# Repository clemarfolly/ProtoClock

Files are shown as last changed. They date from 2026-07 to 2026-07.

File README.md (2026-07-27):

# ProtoClock

Relógio digital com alarme para **PIC16F84**, construído com componentes simples e disponíveis.




## Funcionalidades

- Relógio com 4 displays de 7 segmentos (HH:MM)
- Ponto decimal piscando (1Hz)
- Alarme configurável (hora e minuto)
- Brilho dos displays controlado por PWM
- Calibração fina do timer via osciloscópio

## Hardware

### Componentes

| Componente | Descrição | Quantidade |
|---|---|---|
| PIC16F84 | Microcontrolador | 1 |
| 4017 | Decodificador decimal | 1 |
| 74HC08 | Quad AND gate | 1 |
| BC558 | Transistor PNP | 1 |
| LTS-6960HR | Display 7 segmentos | 4 |
| BZ1 | Buzzer | 1 |
| Y1 | Cristal 4MHz | 1 |
| R1-R3 | 10kΩ (pull-up botões) | 3 |
| R4 | 1kΩ (base transistor) | 1 |
| R5-R12 | 220Ω (segmentos) | 8 |
| C1-C2 | 22pF (cristal) | 2 |
| C3-C4 | 100nF (desacoplamento) | 2 |
| C5 | 10µF (alimentação) | 1 |
| D1-D2 | LED (ponto decimal) | 2 |
| D3 | 1N4007 (proteção buzzer) | 1 |

### Pinagem

```
PIC16F84
┌────────────────────┐
│ 1 RA2   SPK/MIN   │ ← Speaker + Botão MIN (compartilhado)
│ 2 RA3   PONTO/ALR  │ ← LED Ponto + Botão ALARME (compartilhado)
│ 3 RA4   HORA       │ ← Botão HORA
│ 4 MCLR  RESET      │ ← Reset (10k pull-up)
│ 5 VSS   GND        │
│ 6 RB0              │ → Segmento a
│ 7 RB1              │ → Segmento b
│ 8 RB2              │ → Segmento c
│ 9 RB3              │ → PWM Brilho (74HC08)
│ 10 RB4             │ → Segmento d
│ 11 RB5             │ → Segmento e
│ 12 RB6             │ → Segmento f
│ 13 RB7             │ → Segmento g
│ 14 VDD   +5V       │
│ 15 OSC2            │ ← Cristal 4MHz
│ 16 OSC1            │ ← Cristal 4MHz
│ 17 RA0             │ → 4017 CLK
│ 18 RA1             │ → 4017 RESET
└────────────────────┘
```

### Esquemático

O esquemático completo está em [`ProtoClock.pdf`](ProtoClock.pdf).

## Firmware

### Arquivos

| Arquivo | Descrição |
|---|---|
| `ProtoClock84_Otimizado.c` | Código fonte principal (PIC16F84) |
| `ProtoClock.c` | Código original (PIC16F628A, referência) |
| `c84_Otimizado.bat` | Script de compilação |
| `analise_memoria.py` | Análise de uso de memória |

### Estrutura do Código

```
├── Macros e Defines
│   ├── BIT_SET/CLEAR/FLIP/CHECK — manipulação de bits
│   ├── RESET_4017/CLOCK_4017 — controle do decodificador
│   └── SPK_* — configuração do speaker
│
├── Variáveis Globais
│   ├── Relógio: segundo, minuto, hora
│   ├── Alarme: alarme_minuto, alarme_hora, toca_alarme
│   └── Botões: pushFlag[], pushState[]
│
├── ISR (Interrupção)
│   └── Timer0 ~1ms: contagem de tempo, PWM, speaker
│
├── task1() — 61ms
│   ├── Contagem de tempo (segundo/minuto/hora)
│   ├── Leitura de botões com debounce
│   └── Desligamento do alarme
│
├── task2() — 5ms
│   └── Multiplexação dos displays (4017)
│
├── task3() — 201ms
│   └── Ações dos botões (ajuste tempo/alarme)
│
└── main()
    ├── Inicialização
    ├── Loop principal
    └── Lógica do alarme
```

### Compilação

**Requisitos:**
- [SDCC 4.3.0](http://sdcc.sourceforge.net/) (compilador C para PIC)
- [gputils](http://gputils.sourceforge.net/) (montador e linker)

**Passos:**

```bash
# Compilar (Windows)
c84_Otimizado.bat

# Ou manualmente:
sdcc -S --use-non-free -mpic14 -p16f84 ProtoClock84_Otimizado.c
gpasm -I C:\Programas\gputils\header -o ProtoClock84_Otimizado.o -c ProtoClock84_Otimizado.asm
gplink -O 2 -f 0x00 -r -m -s C:\Programas\gputils\lkr\16f84_g.lkr -o ProtoClock84_Otimizado.hex ProtoClock84_Otimizado.o C:\Programas\SDCC\lib\pic14\libsdcc.lib C:\Programas\SDCC\non-free\lib\pic14\pic16f84.lib
```

**Análise de memória:**

```bash
python analise_memoria.py ProtoClock84_Otimizado.map
```

Saída:
```
--- Program Memory ---
  Codigo real:      930 words  (90.8% da ROM)
  Espaco livre:      94 words  (9.2%)

--- Data Memory ---
  RAM utilizada:   57 bytes / 68 bytes
```

### Calibração do Timer

O cristal de 4MHz não é preciso. O Timer0 precisa de calibração fina:

1. Defina `#define CALIBRACAO 1` no código
2. Compile e grave no PIC
3. Meça a frequência no pino RA3 com osciloscópio
4. Ajuste o valor de `cal` em `main()` até obter ~500Hz (2ms período)
5. Remova `#define CALIBRACAO 1`
6. Recompile

Valor padrão: `cal = 10` (ajustado para ~501Hz)

## Botões

| Botão | Pino | Função |
|---|---|---|
| HORA | RA4 | Ajustar hora / Desligar alarme |
| MIN | RA2 | Ajustar minuto / Desligar alarme* |
| ALARME | RA3 | Segurar para ver/ajustar alarme |

### Operação

**Ver horário:** Exibição padrão nos displays.

**Ajustar relógio:**
- Toque rápido em HORA ou MIN = incrementa 1
- Segurar HORA ou MIN = incremento rápido

**Configurar alarme:**
1. Segurar botão ALARME
2. Enquanto segura, tocar HORA ou MIN para ajustar
3. Displays mostram o horário do alarme
4. Soltar ALARME volta ao horário

**Alarme desabilitado:** Hora = 0 e Minuto = 0

**Desligar alarme:** Pressionar HORA ou ALARME enquanto toca.

> \* **Nota:** O botão MIN compartilha pino RA2 com o speaker. Enquanto o alarme toca, o MIN não funciona. Apenas HORA e ALARME podem desligar.

## Limitações de Hardware

### Pinos Compartilhados

| Pino | Funções | Conflito |
|---|---|---|
| RA2 | Speaker + Botão MIN | Botão MIN inoperante durante alarme |
| RA3 | LED Ponto + Botão ALARME | LED desligado durante leitura do botão |

### Soluções implementadas

- **RA2:** Botão MIN é ignorado enquanto `toca_alarme > 0`
- **RA3:** Pin é alternado entre saída (LED) e entrada (botão) ciclicamente a cada ~61ms

### Recomendações para versão futura

- Usar pinos dedicados para speaker e botões
- Adicionar capacitor 100nF entre MCLR e GND para reset mais confiável
- Considerar PIC16F628A (mais pinos, BOR interno)

## Memória

| Recurso | Total | Utilizado | Livre |
|---|---|---|---|
| ROM (programa) | 1024 words | 930 words | 94 words |
| RAM (dados) | 68 bytes | 57 bytes | 11 bytes |

### Distribuição da ROM

| Seção | Tamanho | Descrição |
|---|---|---|
| task1 | 286w | Leitura de botões + relógio |
| task3 | 164w | Ações dos botões |
| main | 145w | Loop principal + alarme |
| ISR | 129w | Interrupção (Timer0) |
| task2 | 124w | Multiplexação display |
| .code | 19w | Biblioteca _gptrget1 |
| obterNumeroDisplay | 18w | Conversão display |
| obterDecimal | 15w | Extração dezena |
| obterUnidade | 13w | Extração unidade |
| numero[10] | 10w | Tabela de segmentos |
| botaoIO[3] | 3w | Mapeamento botões |

## Esquemático

O esquemático completo está disponível em [`ProtoClock.pdf`](ProtoClock.pdf).

Feito com KiCad E.D.A. 9.0.7.

## Licença

Este é um projeto pessoal. Use como quiser.

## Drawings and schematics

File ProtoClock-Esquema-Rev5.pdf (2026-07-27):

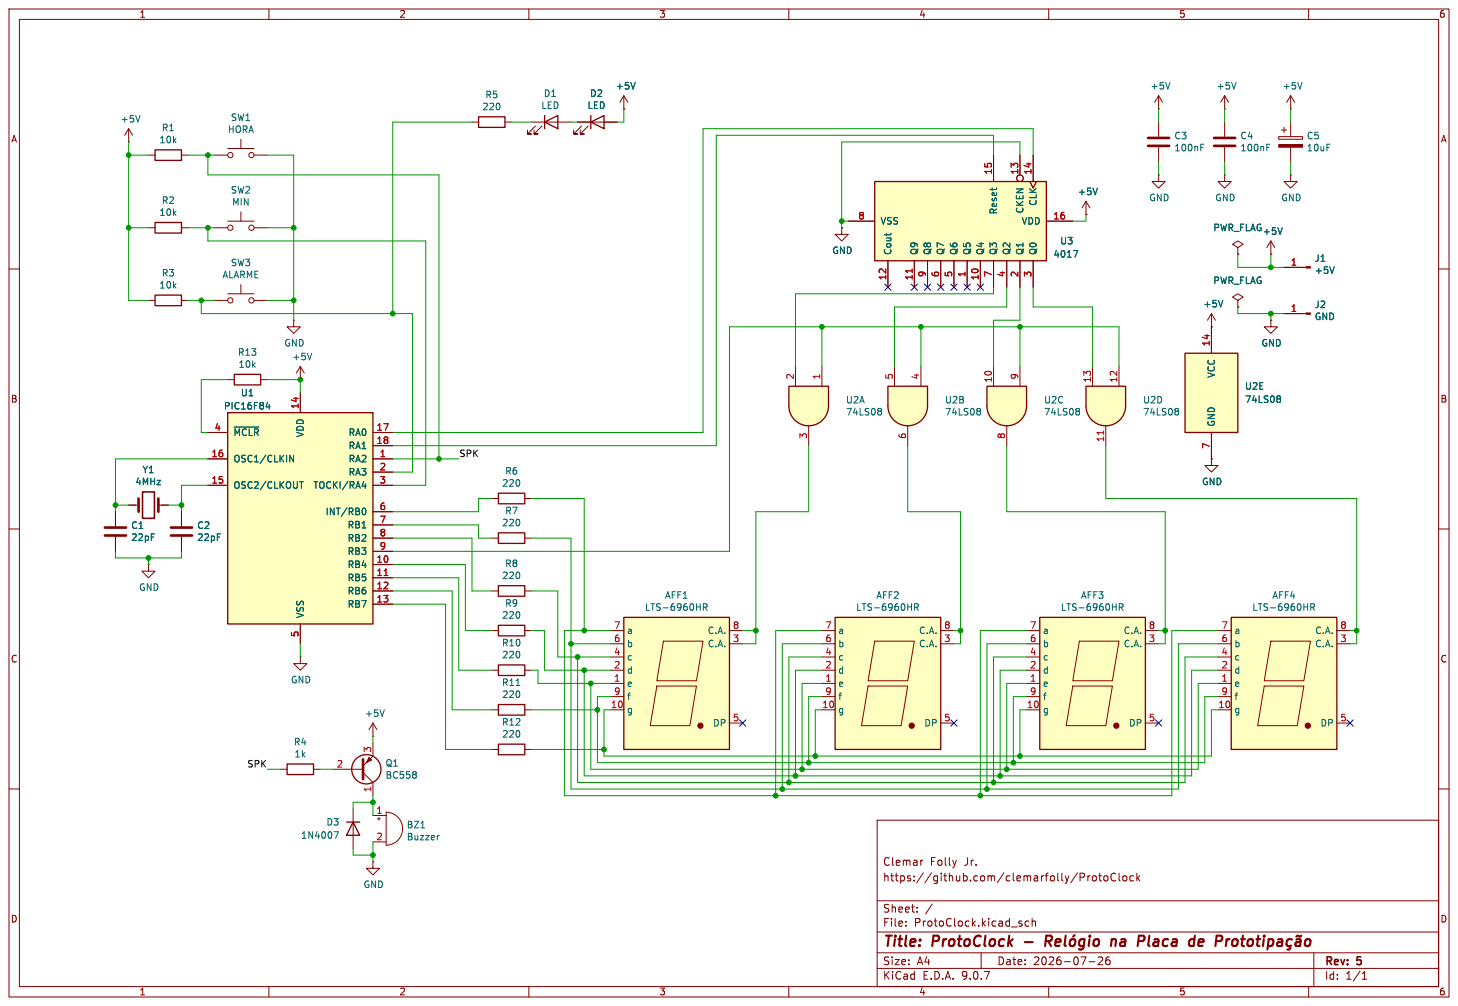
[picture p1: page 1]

Id: 1/1 Title: ProtoClock - þÿRelógio na Placa de þÿPrototipação

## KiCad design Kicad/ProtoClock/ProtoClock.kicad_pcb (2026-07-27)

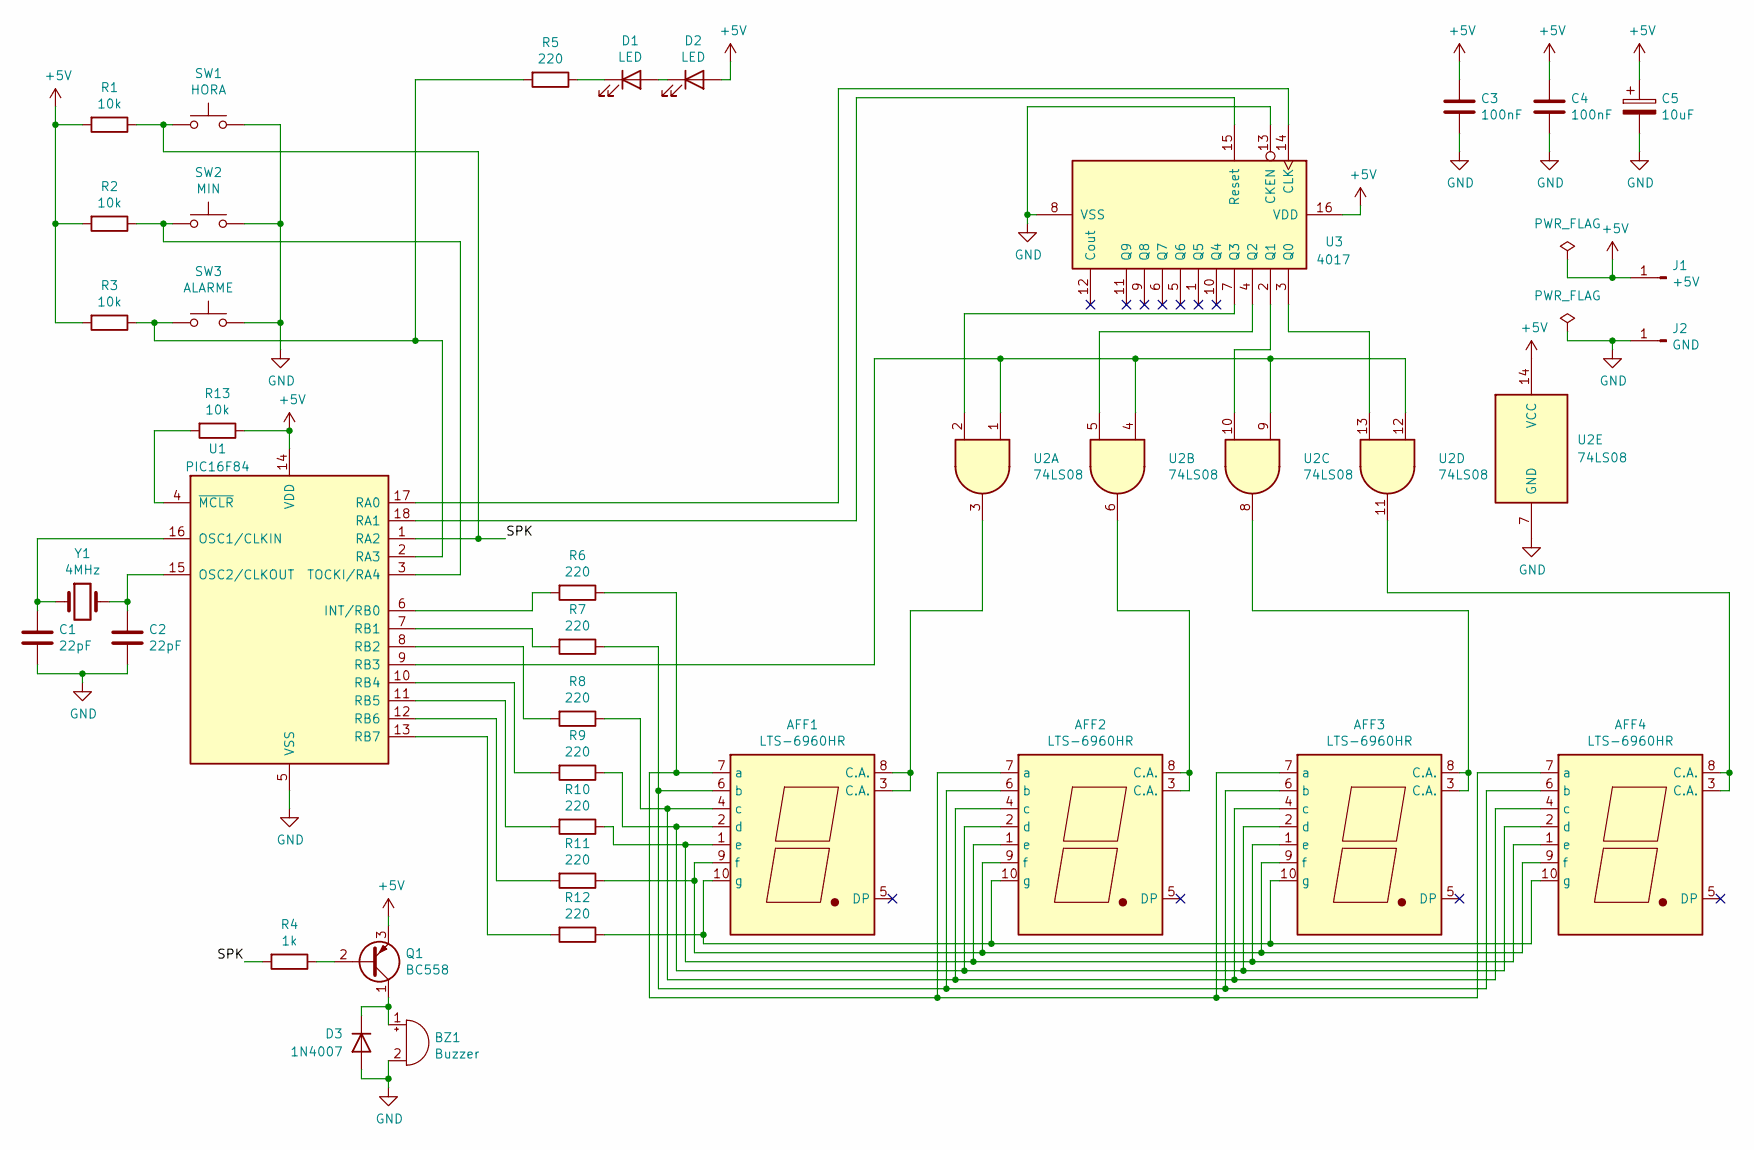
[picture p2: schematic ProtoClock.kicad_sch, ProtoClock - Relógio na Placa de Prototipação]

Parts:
AFF1, AFF2, AFF3, AFF4: LTS-6960HR; 7SegmentLED_LTS6760_LTS6780
BZ1: Buzzer; Buzzer_12x9.5RM7.6
C1, C2: 22pF; C_Disc_D3.0mm_W1.6mm_P2.50mm
C3, C4: 100nF; C_Disc_D3.0mm_W1.6mm_P2.50mm
C5: 10uF; CP_Radial_D5.0mm_P2.50mm
D1, D2: LED; LED_D3.0mm
D3: 1N4007; D_T-1_P5.08mm_Horizontal
J1: +5V; Pin_D1.0mm_L10.0mm
J2: GND; Pin_D1.0mm_L10.0mm
Q1: BC558; TO-92_Inline_Wide
R1, R2, R3, R13: 10k; R_Axial_DIN0204_L3.6mm_D1.6mm_P5.08mm_Horizontal
R4: 1k; R_Axial_DIN0204_L3.6mm_D1.6mm_P5.08mm_Horizontal
R5, R6, R7, R8, R9, R10, R11, R12: 220; R_Axial_DIN0204_L3.6mm_D1.6mm_P5.08mm_Horizontal
SW1: HORA; SW_PUSH_6mm
SW2: MIN; SW_PUSH_6mm
SW3: ALARME; SW_PUSH_6mm
U1: PIC16F84; DIP-18_W7.62mm_Socket_LongPads
U2: 74LS08; DIP-14_W7.62mm_Socket_LongPads
U3: 4017; DIP-16_W7.62mm_Socket_LongPads
Y1: 4MHz; Resonator-2Pin_W10.0mm_H5.0mm

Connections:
+5V: C3.2, C4.1, C5.1, D2.2 (A), J1.1, Q1.3 (E), R1.2, R2.2, R3.2, R13.1, U1.14 (VDD), U2.14 (VCC), U3.16 (VDD)
/SPK: R1.1, R4.2, SW1.1, U1.1 (RA2)
GND: BZ1.2 (-), C1.2, C2.2, C3.1, C4.2, C5.2, D3.2 (A), J2.1, SW1.2, SW2.2, SW3.2, U1.5 (VSS), U2.7 (GND), U3.8 (VSS), U3.13 (CKEN)
unnamed: AFF1.3 (C.A.), AFF1.8 (C.A.), U2.3
unnamed: AFF1.7 (a), AFF2.7 (a), AFF3.7 (a), AFF4.7 (a), R6.1
unnamed: AFF1.6 (b), AFF2.6 (b), AFF3.6 (b), AFF4.6 (b), R7.1
unnamed: AFF1.4 (c), AFF2.4 (c), AFF3.4 (c), AFF4.4 (c), R8.1
unnamed: AFF1.2 (d), AFF2.2 (d), AFF3.2 (d), AFF4.2 (d), R9.1
unnamed: AFF1.1 (e), AFF2.1 (e), AFF3.1 (e), AFF4.1 (e), R10.1
unnamed: AFF1.9 (f), AFF2.9 (f), AFF3.9 (f), AFF4.9 (f), R11.1
unnamed: AFF1.10 (g), AFF2.10 (g), AFF3.10 (g), AFF4.10 (g), R12.1
unnamed: AFF2.3 (C.A.), AFF2.8 (C.A.), U2.6
unnamed: AFF3.3 (C.A.), AFF3.8 (C.A.), U2.8
unnamed: AFF4.3 (C.A.), AFF4.8 (C.A.), U2.11
unnamed: BZ1.1 (+), D3.1 (K), Q1.1 (C)
unnamed: D1.2 (A), D2.1 (K)
unnamed: D1.1 (K), R5.1
unnamed: Q1.2 (B), R4.1
unnamed: R6.2, U1.6 (INT/RB0)
unnamed: C1.1, U1.16 (OSC1/CLKIN), Y1.1
unnamed: C2.1, U1.15 (OSC2/CLKOUT), Y1.2
unnamed: U1.17 (RA0), U3.14 (CLK)
unnamed: U1.18 (RA1), U3.15 (Reset)
unnamed: R3.1, R5.2, SW3.1, U1.2 (RA3)
unnamed: R7.2, U1.7 (RB1)
unnamed: R8.2, U1.8 (RB2)
unnamed: U1.9 (RB3), U2.1, U2.4, U2.9, U2.12
unnamed: R9.2, U1.10 (RB4)
unnamed: R10.2, U1.11 (RB5)
unnamed: R11.2, U1.12 (RB6)
unnamed: R12.2, U1.13 (RB7)
unnamed: R2.1, SW2.1, U1.3 (TOCKI/RA4)
unnamed: R13.2, U1.4 (~MCLR)
unnamed: U2.13, U3.3 (Q0)
unnamed: U2.10, U3.2 (Q1)
unnamed: U2.5, U3.4 (Q2)
unnamed: U2.2, U3.7 (Q3)

Board: 2 copper layers, 36 parts (0 on the bottom side), 37 nets, no tracks yet.

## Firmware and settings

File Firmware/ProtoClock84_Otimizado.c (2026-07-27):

/*
 * ProtoClock - Firmware para PIC16F84
 *
 * Relogio digital com 4 displays de 7 segmentos + ponto decimal.
 * Alarme configuravel.
 * Calibracao de timer via osciloscopio.
 *
 * Hardware (conforme esquematico ProtoClock.sch):
 *   PIC16F84, cristal 4MHz (Y1)
 *   4017 (U3) - decodificador para selecao de display
 *   74HC08/74LS08 (U2A-E) - AND gates para PWM de brilho via RB3
 *   BC558 (Q1) - transistor PNP para buzzer via RA2
 *   2x LEDs (D1, D2) - ponto decimal, compartilhados com botao alarme em RA3
 *
 * Pinagem:
 *   RA0 = 4017 CLK (clock do decodificador)
 *   RA1 = 4017 RESET (reseta para Q0)
 *   RA2 = Speaker (base BC558 via R4 1k) + Botao MIN (SW2, R2 10k pull-up)
 *   RA3 = LED Ponto Decimal (D1/D2 via R5 220R) + Botao ALARME (SW3, R3 10k pull-up)
 *   RA4 = Botao HORA (SW1, R1 10k pull-up)
 *   RB0-RB7 = Segmentos display + RB3 = PWM brilho (74HC08 pin 13)
 *
 * Botoes (ativo baixo, pull-up externo 10k para +5V):
 *   MIN    = RA2  (compartilhado com speaker - LIMITACAO: nao funciona durante alarme)
 *   HORA   = RA4  (dedicado)
 *   ALARME = RA3  (compartilhado com LED ponto)
 *
 * Display:
 *   4x LTS-6960HR (catodo comum)
 *   Selecao via 4017 (Q0-Q3) + 74HC08 AND gates
 *   Brilho via PWM em RB3 (500Hz, ~50% duty cycle)
 *
 * Compilar com SDCC 4.3.0 para PIC16F84.
 * Usar gpasm/gplink (gputils) para montagem e linkagem.
 *
 * Notas:
 *   - O crystal de 4MHz nao e preciso. O valor de cal foi obtido
 *     com osciloscopio para ajuste fino do Timer0 (~1ms).
 *   - Botao MIN (RA2) compartilha pino com speaker. Enquanto o
 *     alarme toca, o speaker alterna RA2, impedindo leitura do botao.
 *     Apenas HORA e ALARME podem desligar o alarme.
 *   - Botao ALARME (RA3) compartilha pino com LED ponto.
 *     O firmware alterna RA3 entre saida (LED) e entrada (botao)
 *     ciclicamente para evitar conflito.
 */

#include <pic16f84.h>
#include <stdint.h>

static __code uint16_t __at (_CONFIG) configword1 = _CP_OFF & _WDT_OFF & _HS_OSC;

//#define CALIBRACAO 1

#define true 1
#define false 0
#define ligado 1
#define desligado 0

/* Estados da maquina de debounce dos botoes */
#define NoPush      1   /* Botao solto, sem atividade */
#define MaybePush   2   /* Possivel pressionamento (aguarda confirmacao) */
#define Pushed      3   /* Botao confirmado pressionado */
#define MaybeNoPush 4   /* Possivel soltura (aguarda confirmacao) */

/* Macros de manipulacao de bits */
#define BIT_SET(a,b)   ((a) |= (1<<(b)))
#define BIT_CLEAR(a,b) ((a) &= ~(1<<(b)))
#define BIT_FLIP(a,b)  ((a) ^= (1<<(b)))
#define BIT_CHECK(a,b) ((a) & (1<<(b)))

#define nop() __asm nop __endasm

/*
 * Macros protegidas com do/while(0).
 * Evita bug se forem usadas dentro de if/else.
 */
#define RESET_4017() \
    do { \
        BIT_SET(PORTA, 1); \
        nop(); \
        nop(); \
        BIT_CLEAR(PORTA, 1); \
    } while (0)

#define CLOCK_4017() \
    do { \
        BIT_SET(PORTA, 0); \
        nop(); \
        nop(); \
        BIT_CLEAR(PORTA, 0); \
    } while (0)

/* PWM do display via RB3 (74HC08 AND gate) */
#define PWM_PIN RB3

/* Ponto decimal (LEDs D1/D2) - compartilhado com botao ALARME */
#define PONTO RA3

/* Speaker (buzzer via BC558 PNP) - compartilhado com botao MIN */
#define SPK_PIN 2
#define SPK_PORT PORTA
#define SPK_PORT_DEF TRISA

/*
 * SPK_IDLE_HIGH = 1: transistor PNP, nivel alto desliga.
 * RA2 em nivel alto  -> base alta  -> PNP corte  -> buzzer off.
 * RA2 em nivel baixo -> base baixa -> PNP conduz -> buzzer on.
 */
#define SPK_IDLE_HIGH 1

/*
 * SPK_COMPARTILHADO_COM_BOTAO = 1: RA2 e usado tanto para speaker
 * quanto para botao MIN. Enquanto o alarme toca, o botao MIN e
 * ignorado porque o speaker esta alternando o pino.
 *
 * LIMITACAO DE HARDWARE: O botao MIN (RA2) nao pode desligar o
 * alarme enquanto ele toca. Apenas HORA (RA4) e ALARME (RA3)
 * podem desligar.
 */
#define SPK_COMPARTILHADO_COM_BOTAO 1

/*
 * Tempo maximo do alarme em segundos.
 * Define por quanto tempo o alarme toca automaticamente.
 * Se 0, toca ate ser desligado manualmente.
 * Se 255 (~4 minutos), toca por bastante tempo.
 * Valor recomendado: 90 (1 minuto e 30 segundos).
 */
#define TEMPO_ALARM_SEG 90

void _sdcc_gsinit_startup(void)
{
    __asm pagesel _main __endasm;
    __asm goto _main __endasm;
}

/*
 * Tabela de segmentos para display de 7 segmentos + ponto.
 * Indice 0-9: digitos 0-9.
 * Bit 7 (MSB) = segmento 'a' (MSB do PORTB).
 *
 * Configuracao do display LTS-6960HR (catodo comum):
 *   RB0=a, RB1=b, RB2=c, RB3=d, RB4=e, RB5=f, RB6=g, RB7=DP
 *
 * Para acender um segmento, o bit correspondente deve ser 0 (ativo baixo).
 * Para apagar, bit = 1.
 *
 * Exemplo: numero[0] = 0b10000000 -> apenas DP apagado (todos ligados = "0")
 *          numero[1] = 0b11110001 -> apenas b,c ligados = "1"
 */
const uint8_t numero[10] = {
    0b10000000,  /* 0: a,b,c,d,e,f ligados */
    0b11110001,  /* 1: b,c ligados */
    0b01000100,  /* 2: a,b,d,e,g ligados */
    0b01100000,  /* 3: a,b,c,d,g ligados */
    0b00110001,  /* 4: b,c,f,g ligados */
    0b00100010,  /* 5: a,c,d,f,g ligados */
    0b00000010,  /* 6: a,c,d,e,f,g ligados */
    0b11110000,  /* 7: a,b,c ligados */
    0b00000000,  /* 8: todos ligados */
    0b00100000   /* 9: a,b,c,d,f,g ligados */
};

/* Variaveis de tempo */
uint8_t segundo;
uint8_t minuto;
uint8_t hora;

/*
 * tempo: contador de milissegundos na ISR.
 * Nao e mais lido diretamente por task1/main.
 */
static volatile uint16_t tempo;

/*
 * ponto_sw: estado software do ponto decimal.
 * 0.5s ligado / 0.5s desligado.
 * Substitui leitura direta de PONTO/RA3 na ISR,
 * evitando conflito com botao de alarme em RA3.
 */
volatile uint8_t ponto_sw;

/*
 * tick_segundo: incrementado pela ISR a cada 1s.
 * task1 consome esse valor para contar segundos.
 * Deve ser lido com GIE=0 para atomicidade (embora uint8_t
 * seja atomico no PIC16F84, e boa pratica).
 */
volatile uint8_t tick_segundo;

/* Display e calibracao */
uint8_t display;
volatile uint8_t cal;

/* Alarme */
uint8_t alarme_minuto;
uint8_t alarme_hora;

/*
 * toca_alarme: contador regressivo de segundos do alarme.
 * Decrementado por task1 a cada segundo.
 * 0 = alarme desligado, >0 = alarme tocando.
 * Quando chega a 0, alarme para automaticamente.
 */
volatile uint8_t toca_alarme;

/*
 * alarme_ajustando: 1 quando o usuario esta ajustando o alarme.
 * Impede disparo enquanto ajusta.
 * Limpo quando botao ALARME e solto.
 */
volatile uint8_t alarme_ajustando;

/*
 * alarme_bloqueado: 1 apos alarme disparar ou ser descartado manualmente.
 * Impede re-disparo no mesmo minuto.
 * E limpo pelo loop principal quando o horario nao mais coincide
 * com o horario do alarme (ou seja, quando o minuto avanca).
 */
volatile uint8_t alarme_bloqueado;

/* Botoes */
#define TOTAL_BOTOES 3

/*
 * Mapeamento dos botoes para pinos do PIC.
 * botaoIO[0] = RA2 = MIN  (compartilhado com speaker)
 * botaoIO[1] = RA4 = HORA (dedicado)
 * botaoIO[2] = RA3 = ALARME (compartilhado com LED ponto)
 */
const uint8_t botaoIO[TOTAL_BOTOES] = {2, 4, 3};

uint8_t pushFlag[TOTAL_BOTOES];
uint8_t pushState[TOTAL_BOTOES];

#define BOTAO_MINUTO  0
#define BOTAO_HORA    1
#define BOTAO_ALARME  2

/* Tempos das tasks (em milissegundos) */
#define TEMPO_TASK1_DEF 61   /* leitura de botoes + relogio (~16Hz) */
#define TEMPO_TASK2_DEF 5    /* multiplexacao do display (~200Hz) */
#define TEMPO_TASK3_DEF 201  /* acoes dos botoes (~5Hz) */

/* Limites do debounce */
#define FLAG_BOTAO_ND     0
#define FLAG_BOTAO_SOLTO  255
#define FLAG_BOTAO_SEGURO (2000 / TEMPO_TASK1_DEF)  /* ~33 = ~2s */

/*
 * Macro: botao ALARME esta pressionado?
 * Verifica se pushFlag esta entre ND e SOLTO.
 * ND=0 (nunca pressionado) e SOLTO=255 (liberado).
 * Valores entre 1 e 254 indicam que o botao esta ou esteve pressionado.
 */
#define BOTAO_ALARME_PRESSIONADO \
    ((pushFlag[BOTAO_ALARME] > FLAG_BOTAO_ND) && \
     (pushFlag[BOTAO_ALARME] < FLAG_BOTAO_SOLTO))

/*
 * Macro: alarme esta inativo (desabilitado)?
 * Quando hora=0 e minuto=0, o alarme esta desabilitado.
 */
#define ALARME_INATIVO \
    ((alarme_hora == 0) && (alarme_minuto == 0))

/*
 * Macro: verifica se o indice i corresponde ao botao
 * compartilhado com o speaker (RA2 = MIN).
 * Retorna 1 se i==0 (BOTAO_MINUTO), 0 caso contrario.
 */
#define SPK_BOTAO_COMPARTILHADO(i) ((i) == 0)

/* Timers das tasks (contagem regressiva, zerados pela ISR) */
volatile uint8_t tempo_task1;
volatile uint8_t tempo_task2;
volatile uint8_t tempo_task3;

/*
 * Rotina de interrupcao.
 * Timer0 configurado para ~1ms (prescaler 1:4, 4MHz, cal=10).
 *
 * Responsabilidades:
 *   1. Decrementar contadores das tasks
 *   2. Contar milissegundos em 'tempo'
 *   3. Detectar transicao de 1 segundo (tick_segundo)
 *   4. Atualizar ponto_sw (0.5s on/off)
 *   5. PWM do display (RB3 toggle a cada 1ms)
 *   6. Alternar speaker quando alarme toca (beep intermitente)
 */
void Intr(void) __interrupt
{
    if (T0IF)
    {
        TMR0 = cal;
        T0IF = 0;

        /* Decrementa contadores das tasks */
        if (tempo_task1 > 0)
            tempo_task1--;

        if (tempo_task2 > 0)
            tempo_task2--;

        if (tempo_task3 > 0)
            tempo_task3--;

        tempo++;

        /* Deteccao de 1 segundo */
        if (tempo >= 1000)
        {
            tempo -= 1000;

            /*
             * Compensacao de atraso do loop principal.
             * Ajustar conforme calibragem no osciloscopio.
             */
            tempo += 2;

            tick_segundo++;
        }

        /* Ponto decimal: 0.5s ligado, 0.5s desligado (1Hz) */
        ponto_sw = (tempo >= 500);

        /*
         * PWM do display via RB3 (74HC08 AND gate).
         * Alterna a cada 1ms = 500Hz, ~50% duty cycle.
         * Controla o brilho dos displays.
         */
        BIT_FLIP(PORTB, 3);

#ifdef CALIBRACAO
        /*
         * Modo calibracao: alterna RA3 para medir frequencia
         * no osciloscopio. Usado para ajustar 'cal'.
         */
        BIT_FLIP(PORTA, 3);
#else
        /*
         * Speaker: alterna RA2 quando alarme toca e ponto esta ligado.
         * Usa ponto_sw (variavel software) em vez de PONTO (RA3)
         * para evitar conflito com botao de alarme em RA3.
         *
         * Frequencia do beep: ~500Hz (1ms toggle = 2ms periodo).
         * O ponto_sw gera beep intermitente (0.5s on, 0.5s off).
         */
        if ((toca_alarme > 0) && ponto_sw)
            BIT_FLIP(SPK_PORT, SPK_PIN);
#endif
    }
}

/*
 * Obtem o digito decimal (dezena) de um numero 0-99.
 * Usa subtracao em loop para evitar divisao (cara em PIC14).
 */
uint8_t obterDecimal(uint8_t num)
{
    uint8_t decimal = 0;

    while (num >= 10)
    {
        decimal++;
        num -= 10;
    }

    return decimal;
}

/*
 * Obtem a unidade de um numero 0-99.
 */
uint8_t obterUnidade(uint8_t num)
{
    while (num >= 10)
    {
        num -= 10;
    }

    return num;
}

/*
 * Converte digito (0-9) para formato do display.
 * Adiciona bit 3 (ponto decimal ligado = segmento apagado).
 */
uint8_t obterNumeroDisplay(uint8_t num)
{
    return numero[num] | (1 << 3);
}

/*
 * Task1: leitura de botoes + contagem de tempo.
 * Executa a cada ~61ms (TEMPO_TASK1_DEF).
 *
 * Responsabilidades:
 *   1. Consumir ticks de segundo da ISR
 *   2. Atualizar segundo/minuto/hora
 *   3. Ler botoes com debounce (maquina de estados)
 *   4. Desligar alarme quando botao e pressionado
 *   5. Controlar LED ponto (RA3)
 */
void task1(void)
{
    uint8_t ps;
    uint8_t btn_pres;
    uint8_t pf;
    uint8_t i;
    uint8_t ticks;

    /* Consome ticks de forma atomica */
    GIE = 0;
    ticks = tick_segundo;
    tick_segundo = 0;
    GIE = 1;

    /* Processa ticks acumulados (normalmente 1, pode ser mais se task1 atrasou) */
    while (ticks > 0)
    {
        ticks--;

        segundo++;

        if (segundo > 59)
        {
            segundo = 0;
            minuto++;
        }

        if (minuto > 59)
        {
            minuto = 0;
            hora++;
        }

        if (hora > 23)
            hora = 0;
    }

    /*
     * Preparacao para leitura do botao ALARME em RA3.
     *
     * RA3 e compartilhado com LED de ponto.
     * Antes de ler como entrada, forca saida baixa para evitar
     * conflito com botao ligado ao GND via R3 (10k).
     */
    PONTO = 0;
    BIT_SET(TRISA, 3);  /* RA3 = entrada para leitura do botao */

    /* Leitura dos botoes com debounce (maquina de estados) */
    for (i = 0; i < TOTAL_BOTOES; i++)
    {
#if SPK_COMPARTILHADO_COM_BOTAO
        /*
         * Se o pino do speaker esta sendo usado como botao,
         * nao le enquanto o alarme toca.
         * Isso evita leituras falsas causadas pela alternancia do buzzer.
         *
         * LIMITACAO: Botao MIN (RA2) nao funciona durante alarme.
         */
        if (SPK_BOTAO_COMPARTILHADO(i) && (toca_alarme > 0))
        {
            pushFlag[i] = 0;
            pushState[i] = 1;  /* MaybePush - mantem estado seguro */
            continue;
        }
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
void main(void)
{
    uint8_t i;

    /*
     * Calibracao do Timer0.
     * Medido com osciloscopio: cal=10 gera ~501Hz (periodo ~1.996ms).
     * Com prescaler 1:4 e 4MHz, Timer0 incrementa a cada 4us.
     * (256-10) * 4us = 984us ~ 1ms.
     * Ajustar conforme crystal utilizado.
     */
    cal = 10;

    /*
     * Configuracao de pinos:
     *   TRISB = 0x00 -> todos RB0-RB7 como saida (segmentos + PWM)
     *   TRISA = 0b00010100 -> RA2(0)=ent MIN, RA4(4)=ent HORA
     *                        RA0(0), RA1(1), RA3(3) como saida inicialmente
     *
     * RA3 e alternado entre saida/entrada ciclicamente pela task1
     * para ler botao ALARME sem conflito com LED ponto.
     */
    TRISB = 0;
    TRISA = 0b00010100;

    PORTB = 0;
    PORTA = 0;

#if !SPK_COMPARTILHADO_COM_BOTAO
    /*
     * Se o speaker for dedicado (nao compartilha pino com botao),
     * ja configura como saida e em nivel seguro.
     */
#if SPK_IDLE_HIGH
    BIT_SET(SPK_PORT, SPK_PIN);
#else
    BIT_CLEAR(SPK_PORT, SPK_PIN);
#endif
    BIT_CLEAR(SPK_PORT_DEF, SPK_PIN);
#endif

    /*
     * Timer0 configurado para ~1ms.
     *
     * Prescaler 1:4, fonte interna (Fosc/4 = 1MHz).
     * Taxa de incremento: 1MHz / 4 = 250kHz -> 4us por incremento.
     * Com cal=10: (256-10) * 4us = 984us ~ 1ms.
     * Ajuste fino feito por 'cal' (medido no osciloscopio).
     */
    OPTION_REG = (OPTION_REG & 0xC0) | 0x01;

    /* Inicializacao do relogio */
    segundo = 0;
    minuto = 0;
    hora = 0;

    tempo = 0;
    ponto_sw = 0;
    tick_segundo = 0;

    /* Inicializacao do alarme (desabilitado: hora=0, minuto=0) */
    alarme_minuto = 0;
    alarme_hora = 0;
    toca_alarme = 0;
    alarme_ajustando = 0;
    alarme_bloqueado = 0;

    /* Inicializacao dos contadores das tasks */
    tempo_task1 = TEMPO_TASK1_DEF;
    tempo_task2 = TEMPO_TASK2_DEF;
    tempo_task3 = TEMPO_TASK3_DEF;

    display = 0;

    /* Inicializacao do estado dos botoes */
    for (i = 0; i < TOTAL_BOTOES; i++)
    {
        pushFlag[i] = FLAG_BOTAO_ND;
        pushState[i] = NoPush;
    }

    /* Inicializa Timer0 com valor calibrado */
    TMR0 = cal;

    /* Liga PWM do display (RB3 = 1 inicialmente) */
    RB3 = 1;

    /* Habilita interrupcao do Timer0 e global */
    T0IE = 1;
    GIE = 1;

    /*
     * Loop principal.
     * Executa as 3 tasks ciclicamente e gerencia o alarme.
     */
    for (;;)
    {
        /* Task1: leitura de botoes + relogio */
        if (tempo_task1 == 0)
        {
            tempo_task1 = TEMPO_TASK1_DEF;
            task1();
        }

        /* Task2: multiplexacao do display */
        if (tempo_task2 == 0)
        {
            tempo_task2 = TEMPO_TASK2_DEF;
            task2();
        }

        /* Task3: acoes dos botoes */
        if (tempo_task3 == 0)
        {
            tempo_task3 = TEMPO_TASK3_DEF;
            task3();
        }

        /*
         * === LOGICA DO ALARME ===
         *
         * Condicoes para disparo:
         *   1. Alarme nao esta inativo (hora != 0 ou minuto != 0)
         *   2. Horario atual coincide com horario do alarme
         *   3. Alarme nao esta bloqueado (ja disparou neste minuto)
         *   4. Alarme nao esta sendo ajustado
         *   5. Botao ALARME nao esta pressionado
         *
         * O alarme dispara CONTINUAMENTE enquanto as condicoes se mantem.
         * O alarme toca por TEMPO_ALARM_SEG segundos (contagem regressiva).
         * Se TEMPO_ALARM_SEG=0, toca ate ser desligado manualmente.
         *
         * O alarme_bloqueado impede re-disparo no mesmo minuto.
         * Ele e limpo quando o horario nao mais coincide (minuto avanca).
         */
        if (ALARME_INATIVO)
        {
            /*
             * Alarme desabilitado (hora=0, minuto=0).
             * Garante que tudo esta desligado e desbloqueado.
             */
            toca_alarme = 0;
            alarme_bloqueado = 0;
            alarme_ajustando = 0;
        }
        else
        {
            if ((hora == alarme_hora) && (minuto == alarme_minuto))
            {
                /*
                 * Horario coincide com alarme.
                 * Dispara se todas as condicoes atenderem.
                 */
                if (!alarme_bloqueado &&
                    !alarme_ajustando &&
                    !BOTAO_ALARME_PRESSIONADO)
                {
                    toca_alarme = TEMPO_ALARM_SEG;
                    alarme_bloqueado = 1;

                    /*
                     * Configura RA2 como saida e ativa speaker.
                     * BIT_SET/SBIT_CLEAR em TRISA e PORTA sao feitos
                     * ANTES de setar toca_alarme para evitar race condition
                     * com a ISR (que pode alternar RA2 entre as operacoes).
                     */
                    BIT_SET(SPK_PORT, SPK_PIN);
                    BIT_CLEAR(SPK_PORT_DEF, SPK_PIN);
                }
            }
            else
            {
                /*
                 * Horario nao coincide: libera alarme para proximo gatilho.
                 * Quando o minuto avanca, alarme_bloqueado e limpo,
                 * permitindo novo disparo no proximo minuto correspondente.
                 */
                alarme_bloqueado = 0;
            }
        }

        /*
         * Desligar speaker quando alarme nao esta tocando.
         *
         * Configura RA2 como saida alta (PNP corte = buzzer off)
         * e depois como entrada (tri-state, mantem nivel alto via pull-up).
         *
         * O speaker so e desligado aqui. Enquanto toca_alarme > 0,
         * a ISR controla o speaker (alternancia para gerar som).
         */
        if (toca_alarme == 0)
        {
            BIT_SET(SPK_PORT, SPK_PIN);
            BIT_SET(SPK_PORT_DEF, SPK_PIN);
        }
    }
}

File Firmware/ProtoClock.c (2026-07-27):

#include <pic16f628a.h>
#include <stdint.h>

static __code uint16_t __at (_CONFIG) configword1 = _CP_OFF & _WDT_OFF & _HS_OSC & _MCLRE_OFF & _LVP_OFF;

#define true 1
#define false 0
#define ligado 1
#define desligado 0

#define NoPush 1 
#define MaybePush 2
#define Pushed 3
#define MaybeNoPush 4

/* a=target variable, b=bit number to act upon 0-n */
#define BIT_SET(a,b) ((a) |= (1<<(b)))
#define BIT_CLEAR(a,b) ((a) &= ~(1<<(b)))
#define BIT_FLIP(a,b) ((a) ^= (1<<(b)))
#define BIT_CHECK(a,b) ((a) & (1<<(b)))

#define nop() __asm nop __endasm

#define RESET_4017() BIT_SET(PORTA, 1); nop(); nop(); BIT_CLEAR(PORTA, 1)
#define CLOCK_4017() BIT_SET(PORTA, 0); nop(); nop(); BIT_CLEAR(PORTA, 0)

#define PONTO RA3
#define SKP RA2
#define SPK_PIN 2
#define SPK_PORT PORTA
#define SPK_PORT_DEF TRISA

void _sdcc_gsinit_startup(void)
{
  __asm pagesel _main __endasm;
  __asm goto _main __endasm;
}

const uint8_t numero[11] = { 0b10000000,
							 0b11110001,
							 0b01000100,
							 0b01100000,
							 0b00110001,
							 0b00100010,
							 0b00000010,
							 0b11110000,
							 0b00000000,
							 0b00100000,
  							 0b11110111};

uint8_t segundo;
uint8_t minuto;
uint8_t hora;
volatile uint16_t tempo;
uint8_t display;

uint8_t alarme_minuto;
uint8_t alarme_hora;
uint8_t toca_alarme;
uint8_t alarme_desligado_manualmente;


#define TOTAL_BOTOES 3
const uint8_t botaoIO[TOTAL_BOTOES] = {2, 4, 5};
uint8_t pushFlag[TOTAL_BOTOES];
uint8_t pushState[TOTAL_BOTOES];

#define BOTAO_MINUTO	0
#define BOTAO_HORA		1
#define BOTAO_ALARME	2

#define FLAG_BOTAO_ND		0
#define FLAG_BOTAO_SOLTO	255
#define FLAG_BOTAO_SEGURO	2000 / TEMPO_TASK1_DEF 

#define BOTAO_ALARME_PRESSIONADO (pushFlag[BOTAO_ALARME] > FLAG_BOTAO_ND && pushFlag[BOTAO_ALARME] < FLAG_BOTAO_SOLTO)
#define ALARME_DESLIGADO (alarme_hora == 0 && alarme_minuto == 0)
							 
#define TEMPO_TASK1_DEF 61
#define TEMPO_TASK2_DEF 10
#define TEMPO_TASK3_DEF 201
 
volatile uint8_t tempo_task1;
volatile uint8_t tempo_task2;
volatile uint8_t tempo_task3;

void Intr(void) __interrupt 0
{
	//timer0 executando a cada 1mS
	if (T0IF)
	{
		TMR0 = 6;
		T0IF = 0;
		
		if (tempo_task1 > 0)
			tempo_task1--;

		if (tempo_task2 > 0)
			tempo_task2--;

		if (tempo_task3 > 0)
			tempo_task3--;
	
		tempo++;
		
		if (toca_alarme && PONTO)
			BIT_FLIP(SPK_PORT, SPK_PIN);
	}
}

void task1()
{
	uint8_t ps, btn_pres, pf;
	uint8_t i;
	
	if (tempo > 1000)
	{
		tempo -= 1000;
		
		segundo++;
		
		if (segundo > 59)
		{
			segundo = 0;
			minuto++;
		}
		
		if (minuto > 59)
		{
			minuto = 0;
			hora++;
		}
		
		if (hora > 23)
			hora = 0;
	}

	for (i = 0; i < TOTAL_BOTOES; i++)
	{
		ps = pushState[i];
		pf = pushFlag[i];
		btn_pres = !BIT_CHECK(PORTA, botaoIO[i]);
		switch (ps)
		{
		case NoPush: 
			if (btn_pres) 
			{
				pf = FLAG_BOTAO_ND;
				ps = MaybePush;
			}
			else 
				ps = NoPush;
			break;
		case MaybePush:
			if (btn_pres)
			{
				ps = Pushed;   
				pf = 1;
			}
			else 
				ps = NoPush;
			break;
		case Pushed:  
			if (btn_pres) 
			{
				ps = Pushed; 

				if (pf < (FLAG_BOTAO_SOLTO-1))
					pf++;
			}
			else 
				ps = MaybeNoPush;    
			break;
		case MaybeNoPush:
			if (btn_pres) 
				ps = Pushed; 
			else 
			{
				ps = NoPush;
				pf = FLAG_BOTAO_SOLTO;
			}
			break;
		}
		pushState[i] = ps;
		pushFlag[i] = pf;
	}
}

void task2()
{
	PORTB = numero[10] | (1<<3);
	CLOCK_4017();
	
	if (display == 0)
	{
		RESET_4017();
		
		if (BOTAO_ALARME_PRESSIONADO)
			PORTB = numero[alarme_minuto % 10] | (1<<3);
		else
			PORTB = numero[minuto % 10] | (1<<3);
		display++;
	}
	else if (display == 1)
	{
		if (BOTAO_ALARME_PRESSIONADO)
			PORTB = numero[alarme_minuto / 10] | (1<<3);
		else
			PORTB = numero[minuto / 10] | (1<<3);
		display++;
	}	
	else if (display == 2)
	{
		if (BOTAO_ALARME_PRESSIONADO)
			PORTB = numero[alarme_hora % 10] | (1<<3);
		else
			PORTB = numero[hora % 10] | (1<<3);
		display++;
	}
	else if (display == 3)
	{
		if (BOTAO_ALARME_PRESSIONADO)
		{
			if ((alarme_hora / 10) == 0)
				PORTB = numero[10] | (1<<3);
			else
				PORTB = numero[alarme_hora / 10] | (1<<3);
		}
		else
		{
			if ((hora / 10) == 0)
				PORTB = numero[10] | (1<<3);
			else
				PORTB = numero[hora / 10] | (1<<3);
		}
		display = 0;
	}
}

void task3()
{
	if (pushFlag[BOTAO_MINUTO] > FLAG_BOTAO_SEGURO)
	{
		if (pushFlag[BOTAO_MINUTO] == FLAG_BOTAO_SOLTO)
			pushFlag[BOTAO_MINUTO] = FLAG_BOTAO_ND;
		
		if (toca_alarme)
		{
			toca_alarme = 0;
			alarme_desligado_manualmente = 1;
		}
		else
		{
			if (BOTAO_ALARME_PRESSIONADO)
			{
				alarme_minuto++;		
				
				if (alarme_minuto > 59)
					alarme_minuto = 0;
			}
			else 
			{
				segundo = 0;
				minuto++;		
				
				if (minuto > 59)
					minuto = 0;
			}
		}
		
	}
	else if (pushFlag[BOTAO_HORA] > FLAG_BOTAO_SEGURO)
	{
		if (pushFlag[BOTAO_HORA] == FLAG_BOTAO_SOLTO)
			pushFlag[BOTAO_HORA] = FLAG_BOTAO_ND;

		if (toca_alarme)
		{
			toca_alarme = 0;		
			alarme_desligado_manualmente = 1;
		}
		else
		{
			if (BOTAO_ALARME_PRESSIONADO)
			{
				alarme_hora++;		
				
				if (alarme_hora > 23)
					alarme_hora = 0;
			}
			else
			{
				hora++;		
				
				if (hora > 23)
					hora = 0;
			}
		}

	}
}

void main()
{
	uint8_t i;
	
	TRISB = 0;
	TRISA = 0b00110100;

	PORTB = 0;
	PORTA = 0;
  
	//timer0 configurado 1ms
	OPTION_REG &= 0xC0 | 0x01;
	TMR0 = 6;
	T0IE = 1;
	GIE = 1;

	RB3 = 1;
  
	tempo_task1 = TEMPO_TASK1_DEF;
	tempo_task2 = TEMPO_TASK2_DEF;
	tempo_task3 = TEMPO_TASK3_DEF;

	display = 0;

	for (i = 0; i < TOTAL_BOTOES; i++)
	{
		pushFlag[i] = FLAG_BOTAO_ND;
		pushState[i] = NoPush;
	}
	
  for (;;) 
  {
    if (tempo_task1 == 0)
	{
		tempo_task1 = TEMPO_TASK1_DEF;
		task1();
	}
	
	if (tempo_task2 == 0)
	{
		tempo_task2 = TEMPO_TASK2_DEF;
		task2();
	}

	if (tempo_task3 == 0)
	{
		tempo_task3 = TEMPO_TASK3_DEF;
		task3();
	}
	
	if (!ALARME_DESLIGADO && !alarme_desligado_manualmente && (hora == alarme_hora) && (minuto == alarme_minuto))
	{
		BIT_CLEAR(SPK_PORT_DEF, SPK_PIN);
		toca_alarme = 1;
	}
	else
	{
		BIT_SET(SPK_PORT_DEF, SPK_PIN);
		toca_alarme = 0;
	}
	
	if (alarme_desligado_manualmente && (minuto > alarme_minuto || (minuto == 0 && alarme_minuto == 59)))
		alarme_desligado_manualmente = 0;
	
	PONTO = (tempo < 500) ? 0 : 1;
	
	
  }
}
